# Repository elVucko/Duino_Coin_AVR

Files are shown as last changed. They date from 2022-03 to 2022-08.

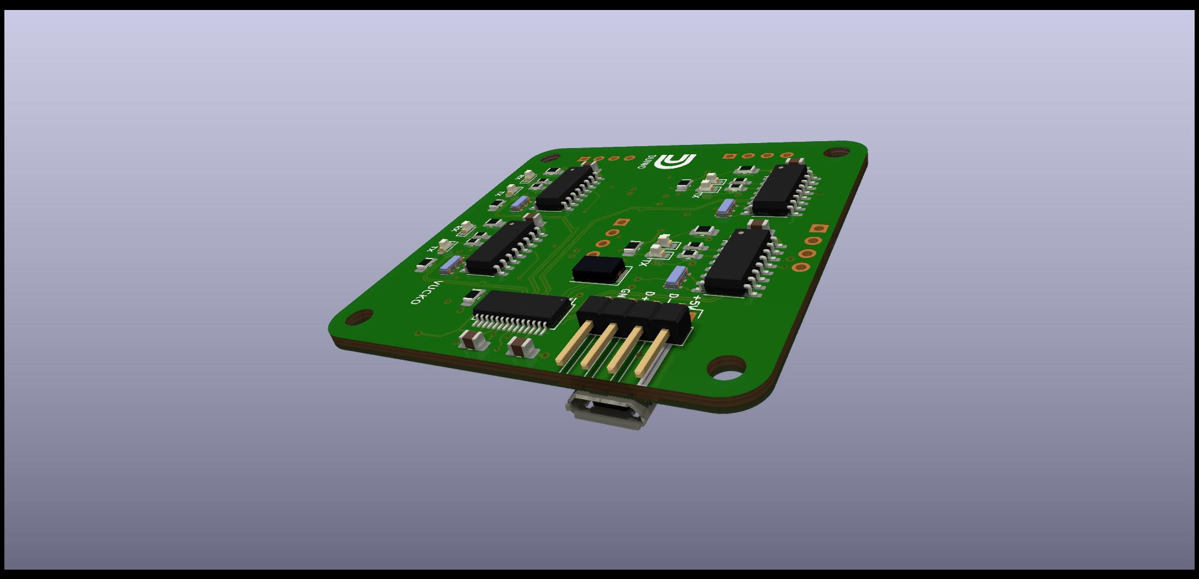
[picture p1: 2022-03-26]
Duino_Coin_AVR/DUINO/CH340G/Images/Duino Coin_5.jpg

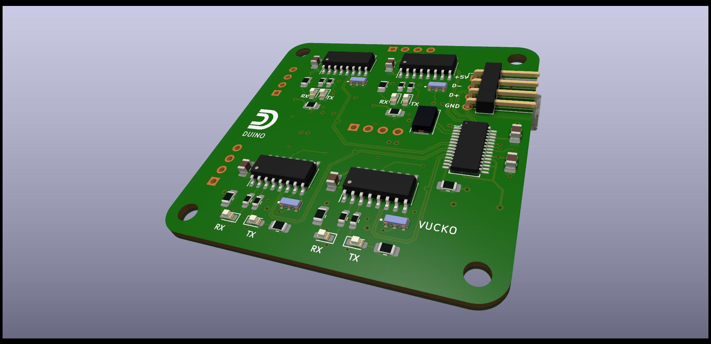
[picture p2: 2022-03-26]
Duino_Coin_AVR/DUINO/CH340G/Images/Duino Coin_4.jpg

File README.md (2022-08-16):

# Read Me 

Duino Coin_3

DUINO



2022-03-26 19_11_12-Duino-Coin AVR Miner (v3 0) - 645_645 accepted shares

---

## Description

This is the simplest DUINO coin mining board design with four Atmega328p and CH340 connected to the FE1.1S USB hub. All that's needed to mine with this board is a micro USB/USB A cable to connect with a computer and the AVR_Miner application installed. 
One version of the PCB is with CH340C and for me, that version works great. But only the CH340C can be used here. Due to difficulties in buying quality chips, I did another design where CH340G is used. On this PCB, both versions of CH340 can be used without any problems. I made this design for fun and I hope it can be useful to someone.

All information regarding the DUINO can be found on the official website:

- https://duinocoin.com/
- https://duinocoin.com/getting-started
- https://github.com/revoxhere/duino-coin/releases/

---

### If you want to support my work

- https://paypal.me/elvuckoo
- https://explorer.duinocoin.com/?search=Vucko

---

## Author Info

- Freelancer - https://www.freelancer.com/hireme/dvucko

[Back To The Top](#read-me-template)

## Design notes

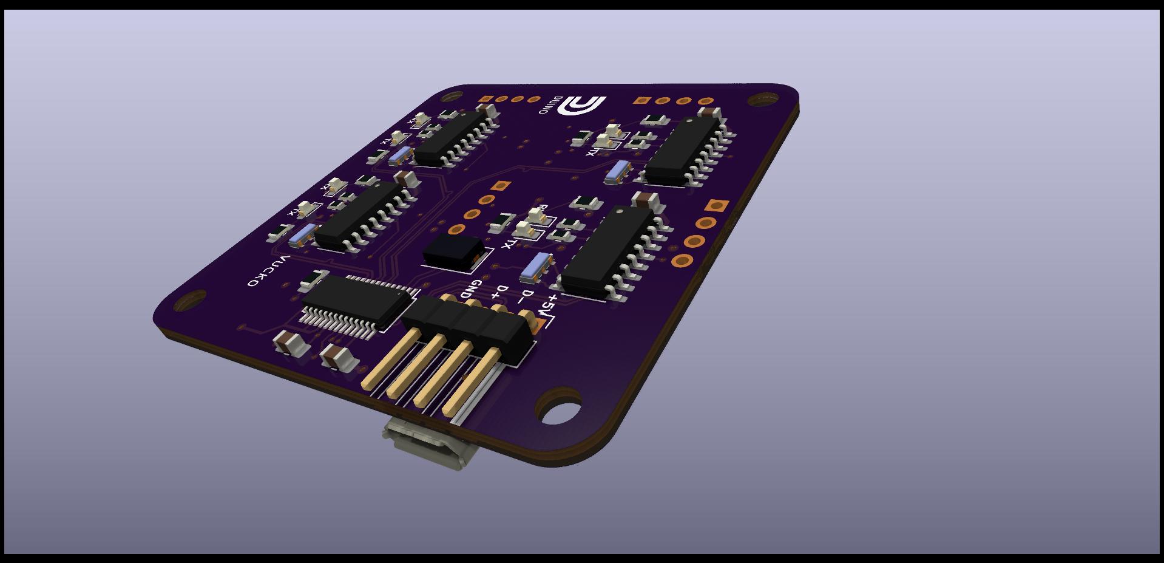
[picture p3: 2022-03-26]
Duino_Coin_AVR/DUINO/CH340G/Images/Duino Coin_1.jpg

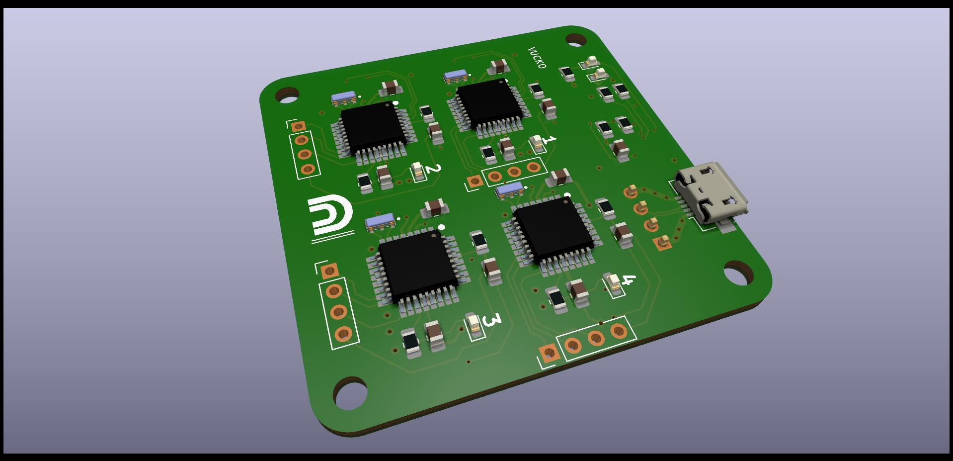
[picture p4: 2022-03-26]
Duino_Coin_AVR/DUINO/CH340G/Images/Duino Coin_3.jpg

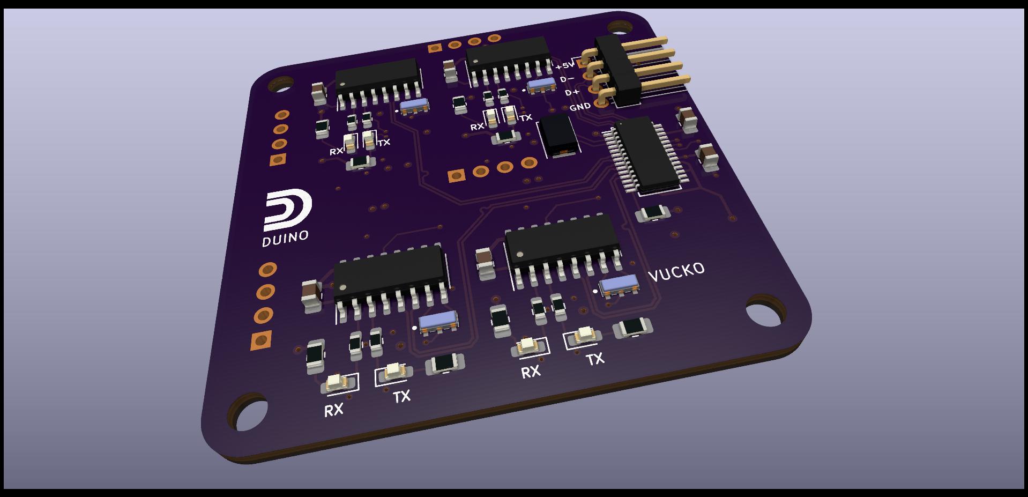
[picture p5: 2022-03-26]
Duino_Coin_AVR/DUINO/CH340G/Images/DUINO.jpg

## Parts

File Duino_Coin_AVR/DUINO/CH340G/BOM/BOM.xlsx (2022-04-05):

Id | Designator | Package | Quantity | Designation | Mouser
1 | C6,C7,C8,C9,C10,C11,C12,C13,C14,C15,C16,C17,C2,C3,C4,C5 | C_0805_2012Metric_Pad1.18x1.45mm | 16 | 0.1u
2 | C19,C21,C23 | C_0805_2012Metric_Pad1.18x1.45mm | 3 | 10u
3 | R17,R18,R19,R20 | R_0805_2012Metric_Pad1.20x1.40mm | 4 | 10k
4 | R21,R22,R23,R24,R30,R9,R10,R11,R12,R13,R14,R15,R16 | R_0805_2012Metric_Pad1.20x1.40mm | 13 | 1k
5 | R25 | R_0805_2012Metric_Pad1.20x1.40mm | 1 | 47k
6 | R26 | R_0805_2012Metric_Pad1.20x1.40mm | 1 | 100k
7 | R29 | R_0805_2012Metric_Pad1.20x1.40mm | 1 | 2.7k
8 | R1,R2,R3,R4,R5,R6,R7,R8 | R_0603_1608Metric_Pad0.98x0.95mm | 8 | 1k
9 | R27,R28 | R_0805_2012Metric_Pad1.20x1.40mm | 2 | 2.2k
10 | D1,D2,D3,D4,D5,D6,D7,D8 | LED_0603_1608Metric_Pad1.05x0.95mm | 8 | Blue
11 | D9,D10,D11,D12 | LED_0603_1608Metric_Pad1.05x0.95mm | 4 | red
12 | D13,D17 | LED_0603_1608Metric_Pad1.05x0.95mm | 2 | Green
13 | U1,U2,U3,U4 | SOIC-16_3.9x9.9mm_P1.27mm | 4 | CH340C
14 | U5 | SSOP-28_3.9x9.9mm_P0.635mm | 1 | FE1.1s
15 | IC1,IC2,IC4,IC3 | QFP80P900X900X120-32N | 4 | ATMEGA328P-AU
16 | Y1,Y2,Y3,Y4 | OSC_CSTCE8M00G55-R0 | 4 | CSTCE16M0V13C99-R0 | 81-CSTCE16M0V13C99R0
17 | Y6,Y7,Y9,Y8 | 81-CSTNE12M0G550000R | 4 | CSTCE12M | 81-CSTNE12M0G550000R
18 | Y5 | Crystal_SMD_5032-2Pin_5.0x3.2mm | 1 | 12MHz | 344-NX5032GA12MLNCD1
19 | J1 | USB_Micro-B_Amphenol_10104110 | 1 | USB_Micro | 649-10104110-0001LF
20 | J2,J3,J5,J6 | PinHeader_1x04_P2.54mm_Vertical | 4 | Conn_01x04
21 | J4 | PinHeader_1x04_P2.54mm_Horizontal | 1 | SS_PG

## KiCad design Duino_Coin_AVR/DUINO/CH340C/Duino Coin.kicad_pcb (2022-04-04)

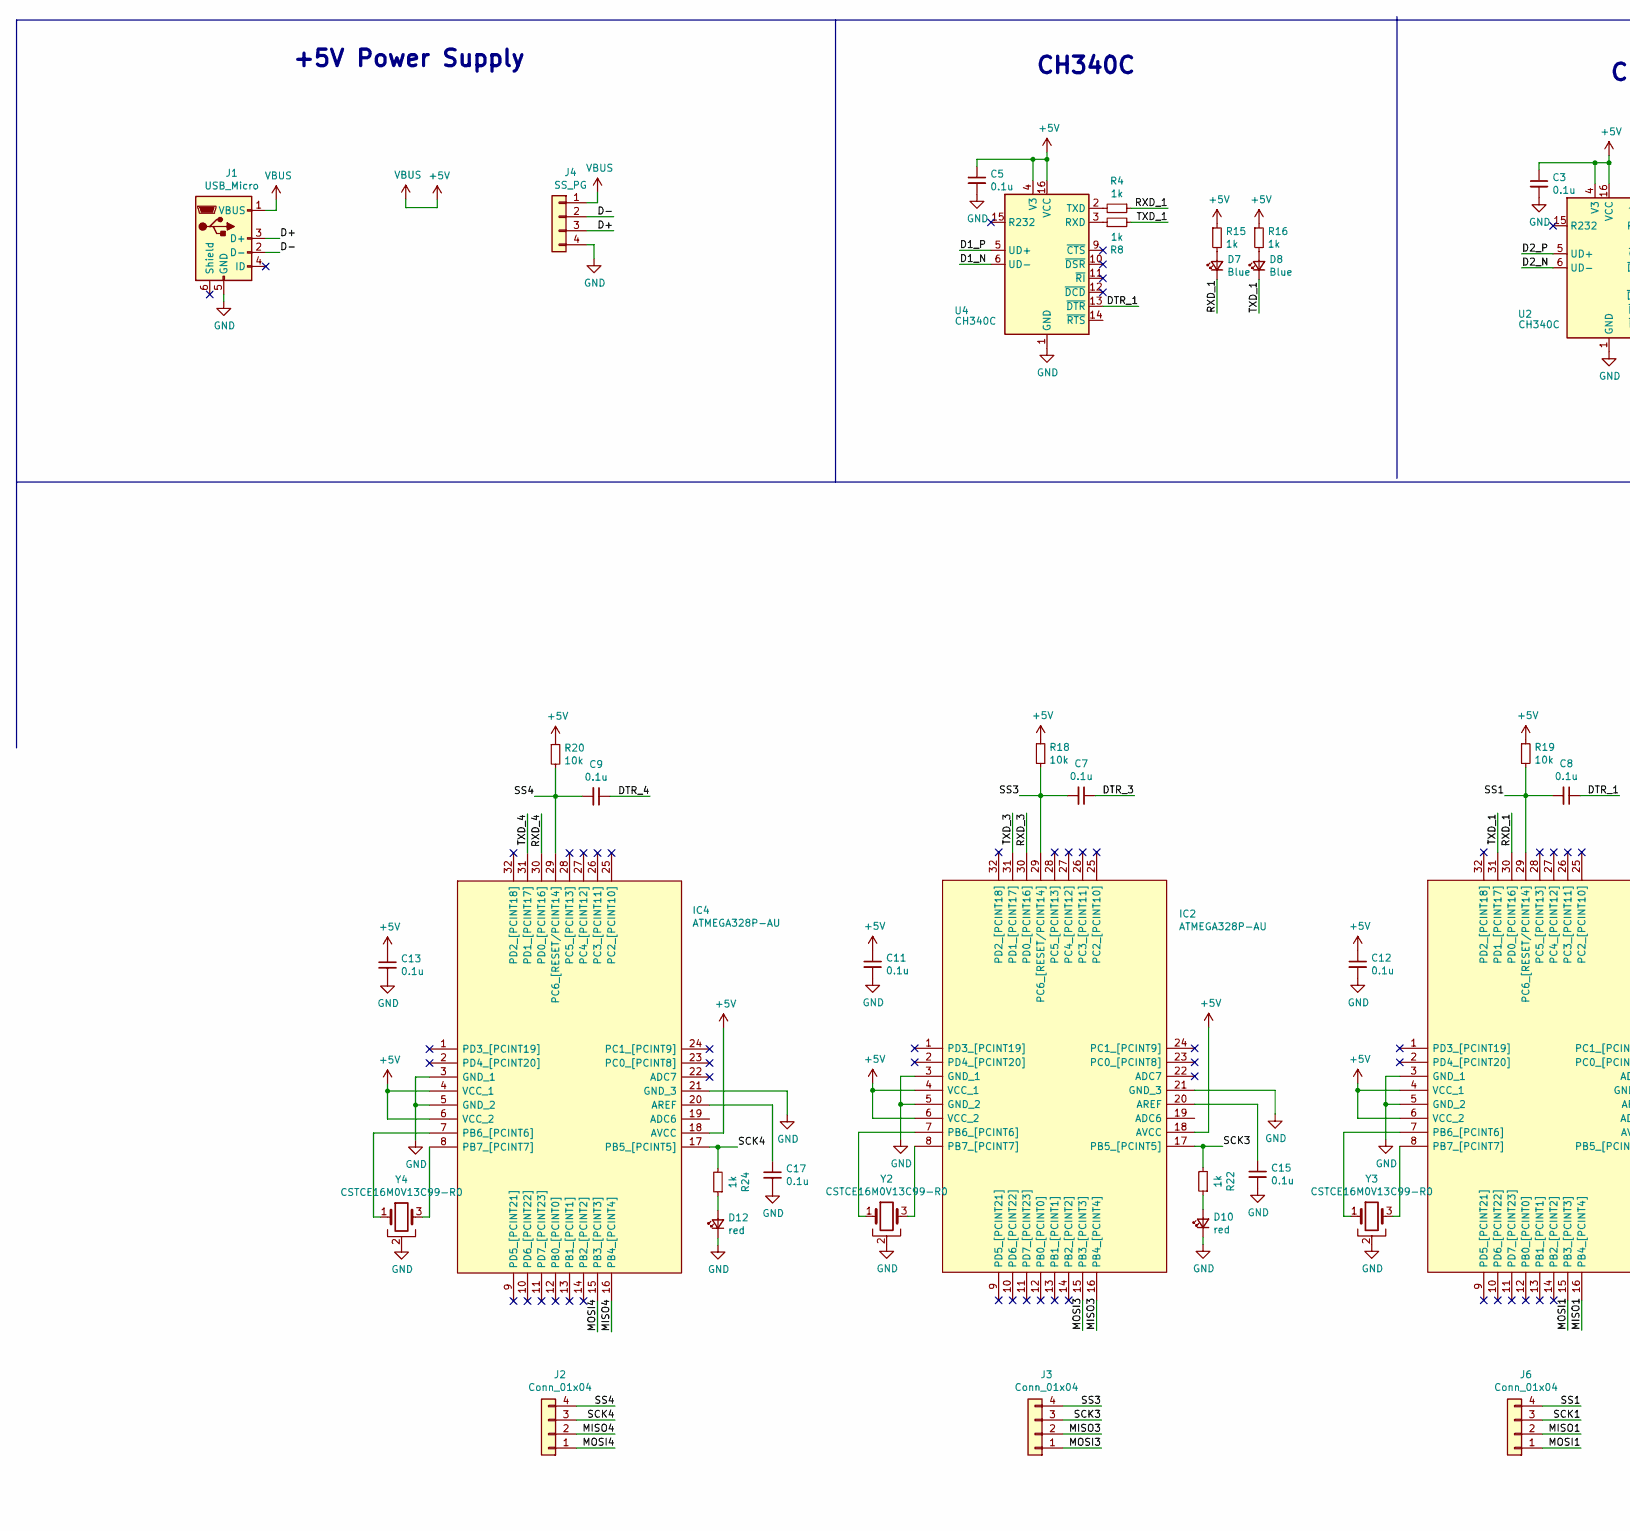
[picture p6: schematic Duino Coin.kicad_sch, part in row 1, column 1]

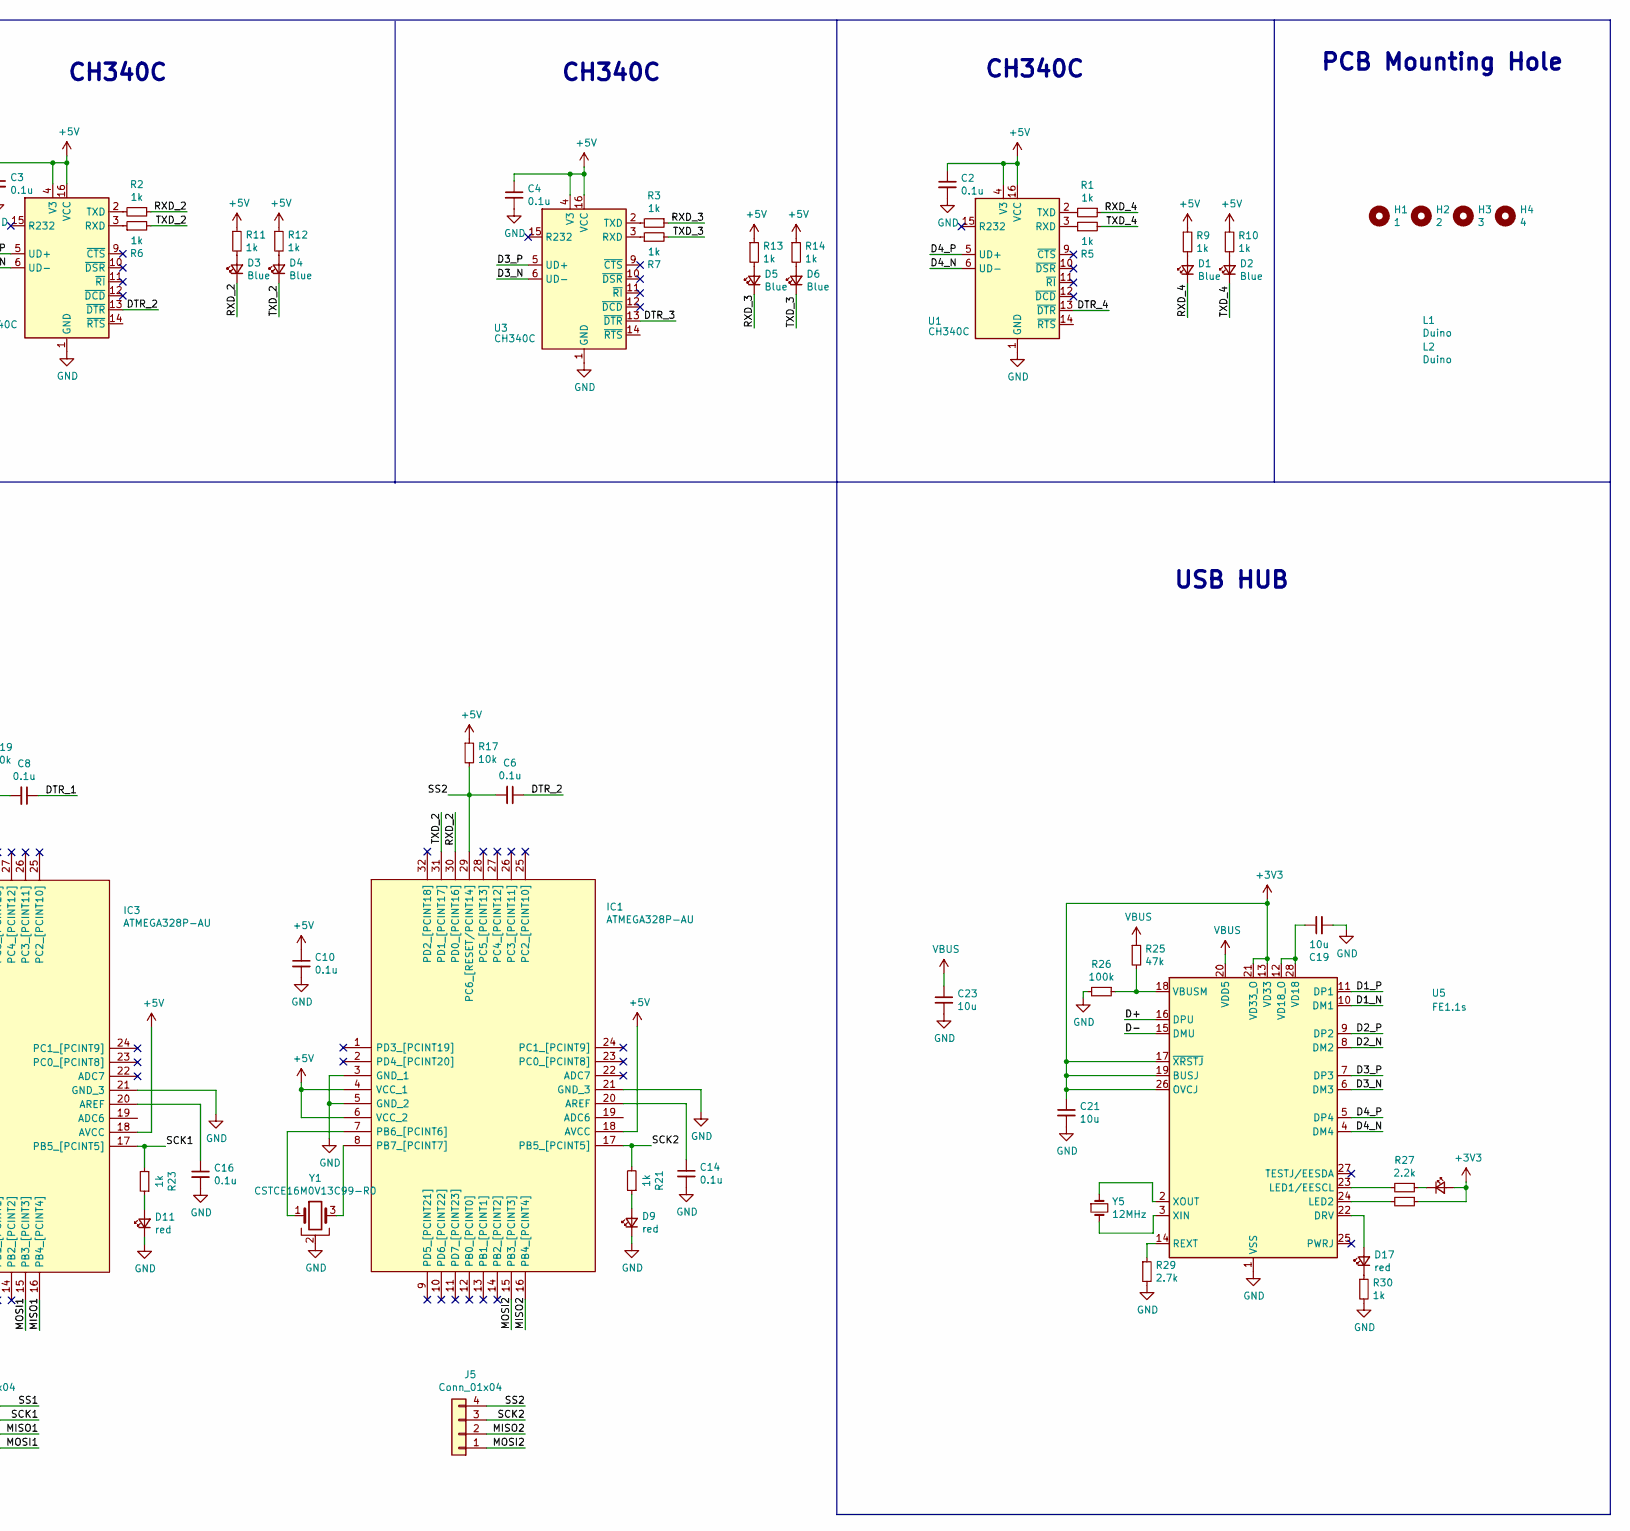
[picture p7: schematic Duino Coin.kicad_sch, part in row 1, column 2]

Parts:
C2, C3, C4, C5, C6, C7, C8, C9, C10, C11, C12, C13, C14, C15, C16, C17: 0.1u; C_0805_2012Metric_Pad1.18x1.45mm_HandSolder
C19, C21, C23: 10u; C_0805_2012Metric_Pad1.18x1.45mm_HandSolder
D1, D2, D3, D4, D5, D6, D7, D8: Blue; LED_0603_1608Metric_Pad1.05x0.95mm_HandSolder
D9, D10, D11, D12, D17: red; LED_0603_1608Metric_Pad1.05x0.95mm_HandSolder
D13: 2; LED_0603_1608Metric_Pad1.05x0.95mm_HandSolder
H1: 1; MountingHole_3.2mm_M3
H2: 2; MountingHole_3.2mm_M3
H3: 3; MountingHole_3.2mm_M3
H4: 4; MountingHole_3.2mm_M3
IC1, IC2, IC3, IC4: ATMEGA328P-AU; QFP80P900X900X120-32N; Manufacturer_Part_Number ATMEGA328P-AU; Mouser Part Number 556-ATMEGA328P-AU
J1: USB_Micro; USB_Micro-B_Amphenol_10104110_Horizontal
J2, J3, J5, J6: Conn_01x04; PinHeader_1x04_P2.54mm_Vertical
J4: SS_PG; PinHeader_1x04_P2.54mm_Horizontal
L1, L2: Duino
R1, R2, R3, R4, R5, R6, R7, R8: 1k; R_0603_1608Metric_Pad0.98x0.95mm_HandSolder
R9, R10, R11, R12, R13, R14, R15, R16, R21, R22, R23, R24, R30: 1k; R_0805_2012Metric_Pad1.20x1.40mm_HandSolder
R17, R18, R19, R20: 10k; R_0805_2012Metric_Pad1.20x1.40mm_HandSolder
R25: 47k; R_0805_2012Metric_Pad1.20x1.40mm_HandSolder
R26: 100k; R_0805_2012Metric_Pad1.20x1.40mm_HandSolder
R27, R28: 2.2k; R_0805_2012Metric_Pad1.20x1.40mm_HandSolder
R29: 2.7k; R_0805_2012Metric_Pad1.20x1.40mm_HandSolder
U1, U2, U3, U4: CH340C; SOIC-16_3.9x9.9mm_P1.27mm
U5: FE1.1s; SSOP-28_3.9x9.9mm_P0.635mm
Y1, Y2, Y3, Y4: CSTCE16M0V13C99-R0; OSC_CSTCE8M00G55-R0
Y5: 12MHz; Crystal_SMD_5032-2Pin_5.0x3.2mm

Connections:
+3V3: C21.1, D13.2 (A), R28.1, U5.13 (VD33), U5.17 (~XRSTJ), U5.19 (BUSJ), U5.21 (VD33_O), U5.26 (OVCJ)
+5V: C2.1, C3.1, C4.1, C5.1, C10.1, C11.1, C12.1, C13.1, C23.1, IC1.4 (VCC_1), IC1.6 (VCC_2), IC1.18 (AVCC), IC2.4 (VCC_1), IC2.6 (VCC_2), IC2.18 (AVCC), IC3.4 (VCC_1), IC3.6 (VCC_2), IC3.18 (AVCC), IC4.4 (VCC_1), IC4.6 (VCC_2), IC4.18 (AVCC), J1.1 (VBUS), J4.1, R9.1, R10.1, R11.1, R12.1, R13.1, R14.1, R15.1, R16.1, R17.1, R18.1, R19.1, R20.1, R25.1, U1.4 (V3), U1.16 (VCC), U2.4 (V3), U2.16 (VCC), U3.4 (V3), U3.16 (VCC), U4.4 (V3), U4.16 (VCC), U5.20 (VDD5)
/D1_N: U4.6 (UD-), U5.10 (DM1)
/D1_P: U4.5 (UD+), U5.11 (DP1)
/D2_N: U2.6 (UD-), U5.8 (DM2)
/D2_P: U2.5 (UD+), U5.9 (DP2)
/D3_N: U3.6 (UD-), U5.6 (DM3)
/D3_P: U3.5 (UD+), U5.7 (DP3)
/D4_N: U1.6 (UD-), U5.4 (DM4)
/D4_P: U1.5 (UD+), U5.5 (DP4)
/D+: J1.3 (D+), J4.3, U5.16 (DPU)
/D-: J1.2 (D-), J4.2, U5.15 (DMU)
/DTR_1: C8.1, U4.13 (~DTR)
/DTR_2: C6.1, U2.13 (~DTR)
/DTR_3: C7.1, U3.13 (~DTR)
/DTR_4: C9.1, U1.13 (~DTR)
/MISO1: IC3.16 (PB4_[PCINT4]), J6.2
/MISO2: IC1.16 (PB4_[PCINT4]), J5.2
/MISO3: IC2.16 (PB4_[PCINT4]), J3.2
/MISO4: IC4.16 (PB4_[PCINT4]), J2.2
/MOSI1: IC3.15 (PB3_[PCINT3]), J6.1
/MOSI2: IC1.15 (PB3_[PCINT3]), J5.1
/MOSI3: IC2.15 (PB3_[PCINT3]), J3.1
/MOSI4: IC4.15 (PB3_[PCINT3]), J2.1
/RXD_1: D7.1 (K), IC3.30 (PD0_[PCINT16]), R4.1
/RXD_2: D3.1 (K), IC1.30 (PD0_[PCINT16]), R2.1
/RXD_3: D5.1 (K), IC2.30 (PD0_[PCINT16]), R3.1
/RXD_4: D1.1 (K), IC4.30 (PD0_[PCINT16]), R1.1
/SCK1: IC3.17 (PB5_[PCINT5]), J6.3, R23.2
/SCK2: IC1.17 (PB5_[PCINT5]), J5.3, R21.2
/SCK3: IC2.17 (PB5_[PCINT5]), J3.3, R22.2
/SCK4: IC4.17 (PB5_[PCINT5]), J2.3, R24.2
/SS1: C8.2, IC3.29 (PC6_[RESET/PCINT14]), J6.4, R19.2
/SS2: C6.2, IC1.29 (PC6_[RESET/PCINT14]), J5.4, R17.2
/SS3: C7.2, IC2.29 (PC6_[RESET/PCINT14]), J3.4, R18.2
/SS4: C9.2, IC4.29 (PC6_[RESET/PCINT14]), J2.4, R20.2
/TXD_1: D8.1 (K), IC3.31 (PD1_[PCINT17]), R8.2
/TXD_2: D4.1 (K), IC1.31 (PD1_[PCINT17]), R6.2
/TXD_3: D6.1 (K), IC2.31 (PD1_[PCINT17]), R7.2
/TXD_4: D2.1 (K), IC4.31 (PD1_[PCINT17]), R5.2
GND: C2.2, C3.2, C4.2, C5.2, C10.2, C11.2, C12.2, C13.2, C14.2, C15.2, C16.2, C17.2, C19.2, C21.2, C23.2, D9.1 (K), D10.1 (K), D11.1 (K), D12.1 (K), IC1.3 (GND_1), IC1.5 (GND_2), IC1.21 (GND_3), IC2.3 (GND_1), IC2.5 (GND_2), IC2.21 (GND_3), IC3.3 (GND_1), IC3.5 (GND_2), IC3.21 (GND_3), IC4.3 (GND_1), IC4.5 (GND_2), IC4.21 (GND_3), J1.5 (GND), J4.4, R26.2, R29.2, R30.2, U1.1 (GND), U2.1 (GND), U3.1 (GND), U4.1 (GND), U5.1 (VSS), Y1.2, Y2.2, Y3.2, Y4.2
unnamed: C14.1, IC1.20 (AREF)
unnamed: C15.1, IC2.20 (AREF)
unnamed: C16.1, IC3.20 (AREF)
unnamed: C17.1, IC4.20 (AREF)
unnamed: C19.1, U5.12 (VD18_O), U5.28 (VD18)
unnamed: D1.2 (A), R9.2
unnamed: D2.2 (A), R10.2
unnamed: D3.2 (A), R11.2
unnamed: D4.2 (A), R12.2
unnamed: D5.2 (A), R13.2
unnamed: D6.2 (A), R14.2
unnamed: D7.2 (A), R15.2
unnamed: D8.2 (A), R16.2
unnamed: D9.2 (A), R21.1
unnamed: D10.2 (A), R22.1
unnamed: D11.2 (A), R23.1
unnamed: D12.2 (A), R24.1
unnamed: D13.1 (K), R27.1
unnamed: D17.1 (K), R30.1
unnamed: D17.2 (A), U5.22 (DRV)
unnamed: IC1.7 (PB6_[PCINT6]), Y1.1
unnamed: IC1.8 (PB7_[PCINT7]), Y1.3
unnamed: IC2.7 (PB6_[PCINT6]), Y2.1
unnamed: IC2.8 (PB7_[PCINT7]), Y2.3
unnamed: IC3.7 (PB6_[PCINT6]), Y3.1
unnamed: IC3.8 (PB7_[PCINT7]), Y3.3
unnamed: IC4.7 (PB6_[PCINT6]), Y4.1
unnamed: IC4.8 (PB7_[PCINT7]), Y4.3
unnamed: R1.2, U1.2 (TXD)
unnamed: R2.2, U2.2 (TXD)
unnamed: R3.2, U3.2 (TXD)
unnamed: R4.2, U4.2 (TXD)
unnamed: R5.1, U1.3 (RXD)
unnamed: R6.1, U2.3 (RXD)
unnamed: R7.1, U3.3 (RXD)
unnamed: R8.1, U4.3 (RXD)
unnamed: R25.2, R26.1, U5.18 (VBUSM)
unnamed: R27.2, U5.23 (LED1/EESCL)
unnamed: R28.2, U5.24 (LED2)
unnamed: R29.1, U5.14 (REXT)
unnamed: U5.2 (XOUT), Y5.1
unnamed: U5.3 (XIN), Y5.2

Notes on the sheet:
CH340C
+5V Power Supply
PCB Mounting Hole
USB HUB

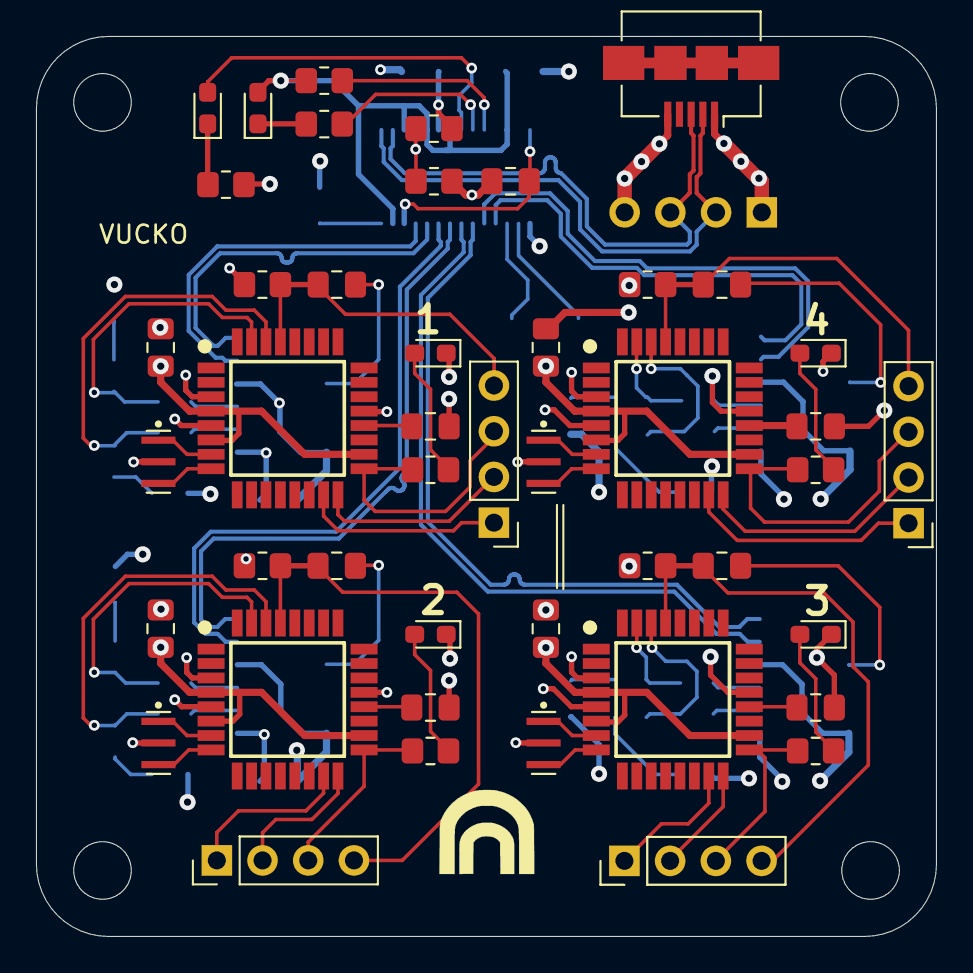
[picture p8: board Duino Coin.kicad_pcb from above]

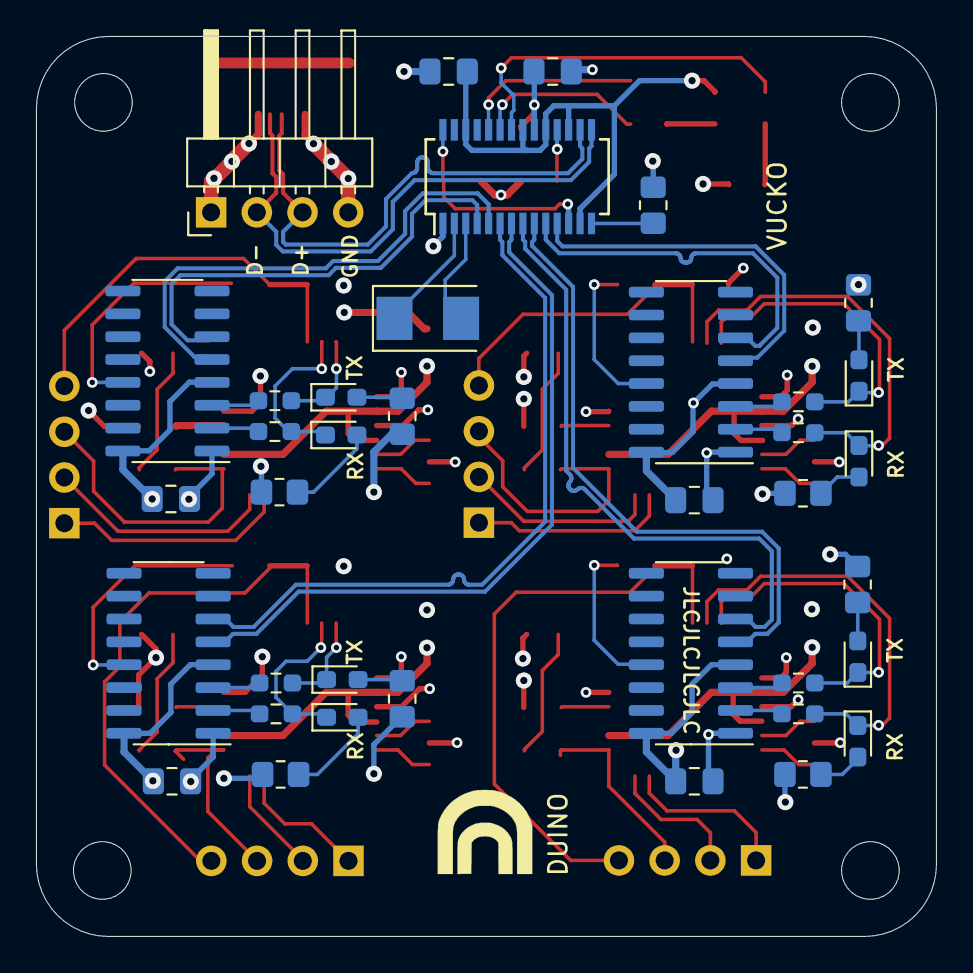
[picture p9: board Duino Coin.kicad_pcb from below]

Board: 4 copper layers, 50.0 x 50.0 mm, 89 parts (39 on the bottom side), 83 nets.

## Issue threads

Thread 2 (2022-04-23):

CPL File

iTzNikolovich, 2022-04-23:
Hi, can you add the CPL? I need it for JLCPCB
There's a sample [https://jlcpcb.com//video/JLCSMT_Sample_CPL1.xlsx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](url)

elVucko, 2022-05-01:
I'm sorry, I was very busy and I didn't get to answer you earlier. I will add a CPL file in the coming days.

Closed 2022-05-02.
